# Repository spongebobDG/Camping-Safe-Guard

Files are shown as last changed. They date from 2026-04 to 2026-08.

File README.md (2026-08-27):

# Camping Safe Guard

ESP32·가스·온습도 센서와 TinyML을 이용해 캠핑 환경의 일산화탄소 위험을 감지하고 사용자에게 전달하는 캡스톤 프로젝트입니다.

> An embedded safety prototype that combines ESP32 sensor nodes, MQ-9 gas sensing, wireless telemetry, and TensorFlow Lite Micro experiments.

| 구분 | 내용 |
|---|---|
| 기간 | 2025.09–2025.12 |
| 구성 | 4인 개발팀 · 팀장 |
| 담당 | 시스템 설계, 모델 경량화, ESP32 펌웨어, ESP-NOW, 회로·3D 프린팅 케이스 제작 |
| 학술 성과 | KCC 2026 논문 심사 통과·포스터 세션 발표, 제1저자 |
| 논문 | 「제한된 엣지 환경에서의 일산화탄소 조기 경보를 위한 경량 1D-CNN 기반 웨어러블 시스템 설계」 |

## 프로젝트 요약

| 구분 | 내용 |
|---|---|
| 목적 | 캠핑 공간의 CO·온습도 상태 감지와 위험 단계 전달 |
| MCU | ESP32, ESP32-C3 |
| 센서 | MQ-9, DHT11 |
| 통신 | ESP-NOW 중심, BLE·모바일 UI prototype 실험 |
| Edge AI | TensorFlow Lite Micro 기반 시계열 위험도 추론 실험 |
| 기타 | OLED 표시, 모바일 HTML prototype, 3D printed enclosure, 배터리 승압 효율 자료 |

## 시스템 구조

```text
MQ-9 / DHT11
      │
      ▼
ESP32 sensor node ── calibration / TinyML inference ── status decision
      │                                                   │
      ├── OLED local display                              │
      └── ESP-NOW / BLE ──> ESP32-C3 receiver / mobile prototype
```

## 저장소에서 확인할 수 있는 구현

- MQ-9 clean-air calibration과 CO PPM 변환
- 온도·습도·가스 측정값을 결합한 상태 데이터
- sliding window 입력과 TensorFlow Lite Micro inference
- 정상·주의·위험 단계 판단 및 OLED 표시
- ESP-NOW 기반 센서 노드–수신 노드 통신 실험
- ESP32/ESP32-C3 케이스 STL과 18650 배터리 승압 효율 자료

가장 발전된 TinyML 실험 firmware는 [`src/esp32_ino/esp32_v4_ai/esp32_v4_ai.ino`](src/esp32_ino/esp32_v4_ai/esp32_v4_ai.ino)에 있습니다. 저장소에는 개발 과정의 여러 hardware revision이 함께 남아 있으므로 모든 `.ino` 파일을 최종 firmware로 해석하면 안 됩니다.

## TinyML 경로

```text
MQ-9 raw sequence
    └── normalization
        └── 60-step input buffer
            └── TFLite Micro inference
                └── probability + calibrated PPM safety rule
```

기준 firmware의 `N_STEPS = 60`이며, 2초 주기 샘플을 가정하면 최근 120초의 흐름을 입력으로 사용합니다.

## MCU 메모리 문제와 모델 전환

초기 LSTM 모델은 약 174KB로, 센서·ESP-NOW·OLED가 함께 동작하는 ESP32 환경에서 텐서 메모리 할당 문제가 발생했습니다. 캠핑 사고의 전조에서 중요한 것은 장기 상태보다 단시간의 농도 상승 패턴이라고 판단해 순환 구조를 1D-CNN으로 바꿨습니다. KCC 논문과 지원 포트폴리오에는 약 10KB까지 줄인 결과를 보고했습니다.

공개 저장소에는 개발 과정의 174KB 모델과 3–4KB대 실험 artifact 등 여러 revision이 함께 있습니다. 논문의 174KB→약 10KB 비교를 한 번에 재현하는 학습 notebook과 release는 아직 고정되어 있지 않으므로, 이 값은 **논문 보고 결과**로 표시하며 저장소 benchmark처럼 표현하지 않습니다.

## 하이브리드 안전 판단

| CO 구간 | 판단 방식 |
|---|---|
| 15 PPM 미만 | 센서 잡음 구간으로 보고 AI 결과를 사용하지 않음 |
| 15–50 PPM | AI 확률 0.5 초과 시 주의, 0.8 초과 시 위험 |
| 50–400 PPM | 규칙이 주의를 기본 보장하고 AI가 위험으로 격상 |
| 400 PPM 이상 | AI 결과와 무관하게 위험 상태 강제 |

합성 데이터 기반 HIL 급성 누출 시나리오에서는 절대 안전망 도달보다 약 8.5초 먼저 최고 경보가 발생했습니다. 이 값은 실제 CO 환경이나 인증 시험에서 얻은 성능이 아닙니다.

## 학술 성과

- 캡스톤 프로젝트
- 한국컴퓨터종합학술대회(KCC 2026) 논문 심사 통과
- KCC 2026 포스터 세션 발표
- 4인 개발팀 팀장·제1저자, 멘토·지도교수 포함 총 6인 저자

논문 제목은 「제한된 엣지 환경에서의 일산화탄소 조기 경보를 위한 경량 1D-CNN 기반 웨어러블 시스템 설계」입니다. 수상 실적은 없으며, 배포 권한이 확인되지 않은 학회 PDF는 저장소에 복제하지 않습니다.

## 디렉터리 안내

```text
Camping-Safe-Guard/
├── src/esp32_ino/        # ESP32/ESP32-C3 firmware revisions, model, training CSV
├── src/firmware/         # 초기 정리 과정에서 복제된 firmware tree
├── src/mobile-app/       # mobile display prototype
├── hardware/3d-models/   # enclosure STL revisions
└── docs/                 # battery boost efficiency data
```

`src/esp32_ino/`와 `src/firmware/esp32_ino/`의 중복은 후속 정리 대상입니다. 면접에서는 기준 firmware 경로와 revision별 목적을 먼저 설명합니다.

## 현재 한계

- 기준 hardware revision과 final firmware가 release로 고정되어 있지 않습니다.
- 센서 교정 환경과 실제 CO 기준 장비를 사용한 비교 시험이 문서화되지 않았습니다.
- 모델 평가와 MCU resource benchmark가 재현 가능한 형태로 정리되지 않았습니다.
- 약 8.5초 조기 경보는 합성 데이터 기반 HIL 결과이며 실환경 인증 성능이 아닙니다.
- 모바일 화면은 제품 앱이 아니라 prototype입니다.

## 안전 고지

이 프로젝트는 교육·연구용 prototype입니다. 인증된 일산화탄소 경보기, 환기 설비 또는 상용 안전 장치를 대체하지 않습니다.

## 면접용 요약

- **30초:** “4인 팀장으로 가스·온습도 센서부터 ESP32 edge inference, ESP-NOW, 회로와 케이스 제작까지 연결했고, 제1저자로 KCC 2026 포스터 세션에서 발표했습니다.”
- **기술 질문:** 센서 calibration, raw ADC와 PPM의 차이, TinyML 입력 정규화, 통신 장애 시 로컬 경보 유지 여부를 중심으로 설명합니다.

## Related Portfolio

[ROS 2 Robot Systems Software Portfolio](https://github.com/spongebobDG/robotics-software-portfolio)

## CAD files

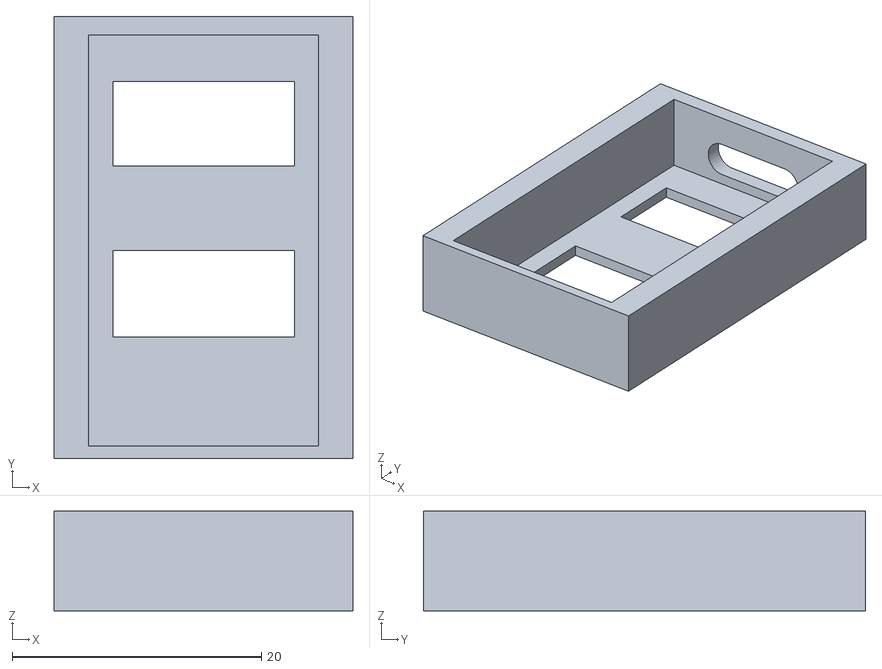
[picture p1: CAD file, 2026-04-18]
hardware/3d-models/esp32-c3_v2/esep32-c3_ctype.stl
24.0 x 35.5 x 8.00

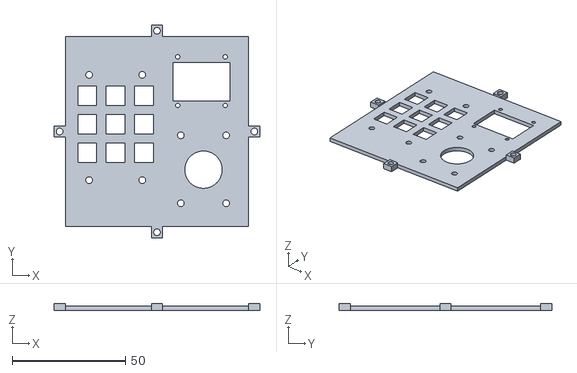
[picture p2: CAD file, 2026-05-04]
hardware/3d-models/esp32_v1/esp32_v1_2F_1.stl
91.0 x 94.0 x 3.00

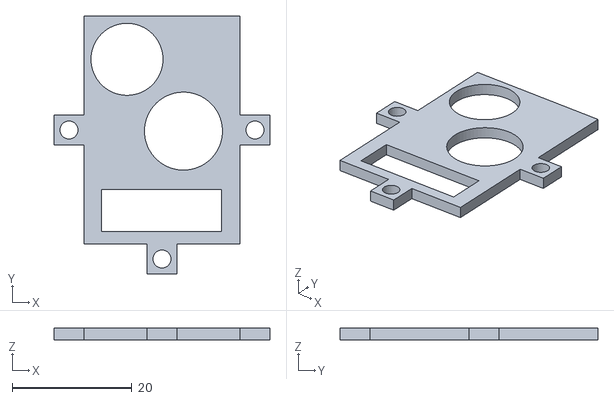
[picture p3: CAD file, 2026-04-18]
hardware/3d-models/esp32-c3_v2/esp32-c3_2F_v2.stl
36.0 x 43.0 x 2.00

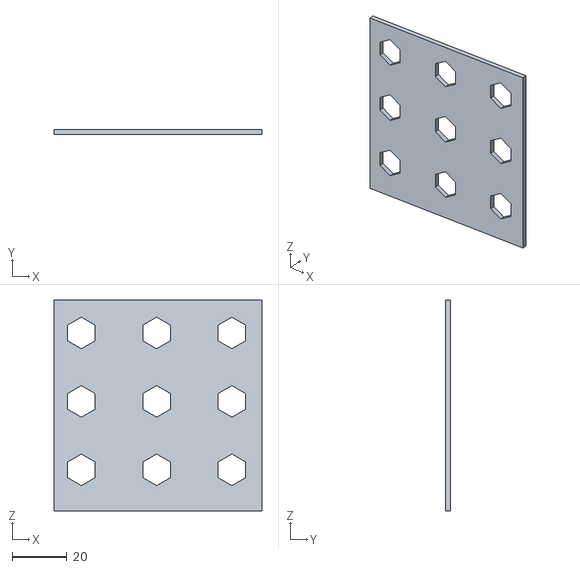
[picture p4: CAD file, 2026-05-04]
hardware/3d-models/esp32_v1/esp32_v1_-1F_1.stl
76.0 x 2.00 x 77.0

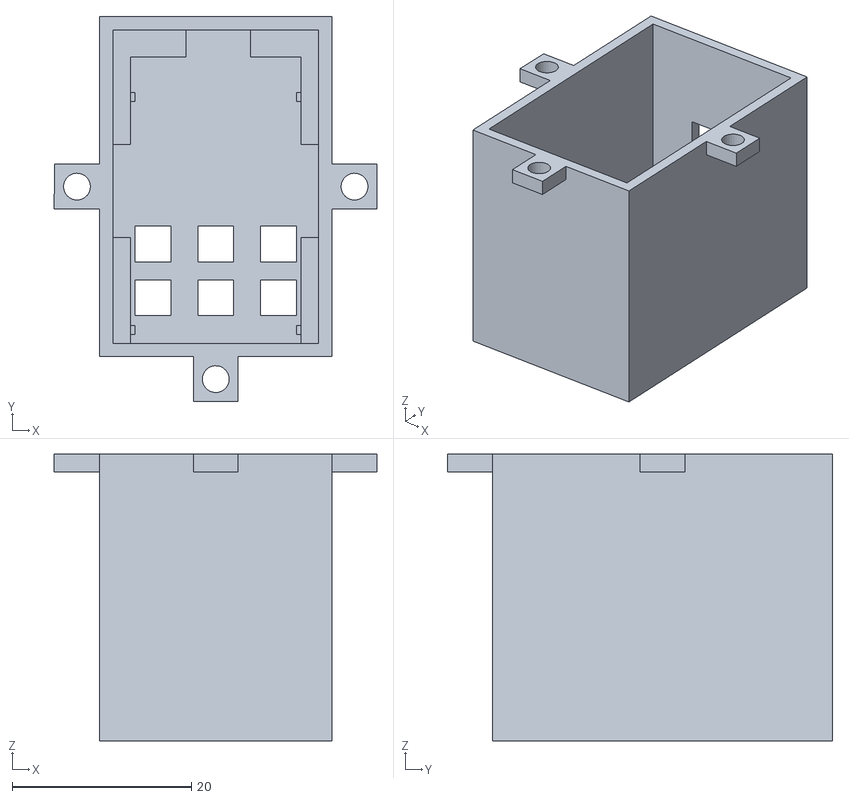
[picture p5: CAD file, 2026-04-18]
hardware/3d-models/esp32-c3_v2/esp32-c3_1F_v2.stl
36.1 x 43.0 x 32.0

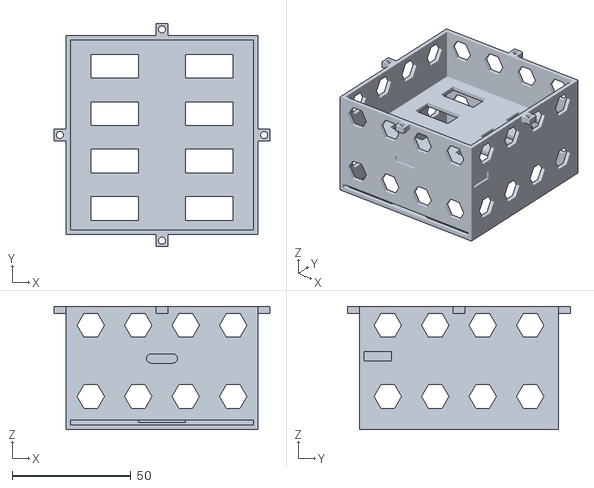
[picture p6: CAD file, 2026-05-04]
hardware/3d-models/esp32_v1/esp32_v1_1.stl
91.0 x 94.0 x 52.0

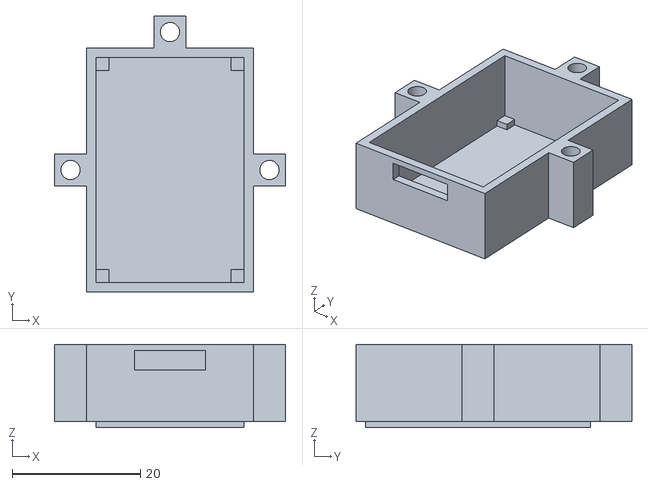
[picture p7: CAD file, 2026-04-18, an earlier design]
hardware/3d-models/esp32-c3_v1/esp32-c3_2F.stl
36.0 x 43.0 x 13.0

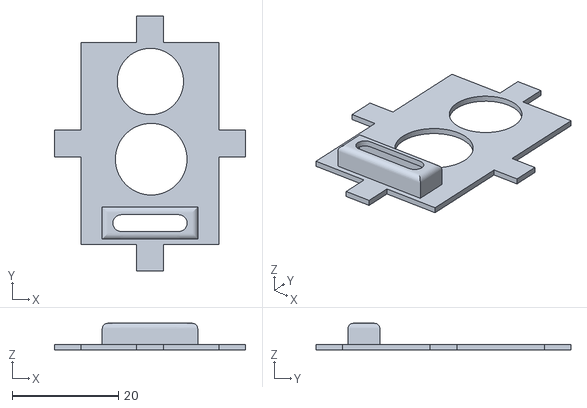
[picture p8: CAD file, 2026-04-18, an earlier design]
hardware/3d-models/esp32-c3_v1/esp32-3_4F.stl
36.0 x 48.0 x 5.00

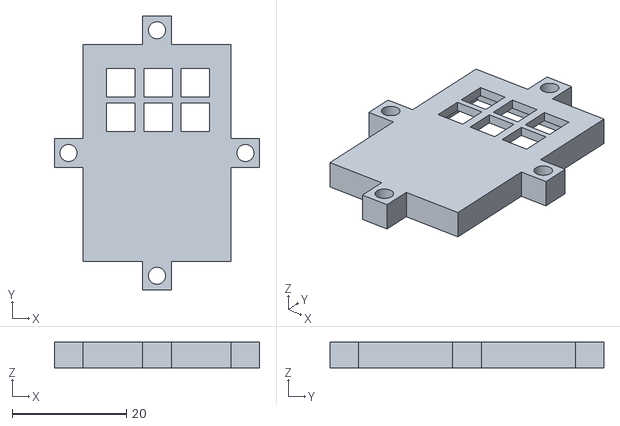
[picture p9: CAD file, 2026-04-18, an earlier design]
hardware/3d-models/esp32-c3_v1/esp32-c3_1F.stl
36.0 x 48.0 x 4.50

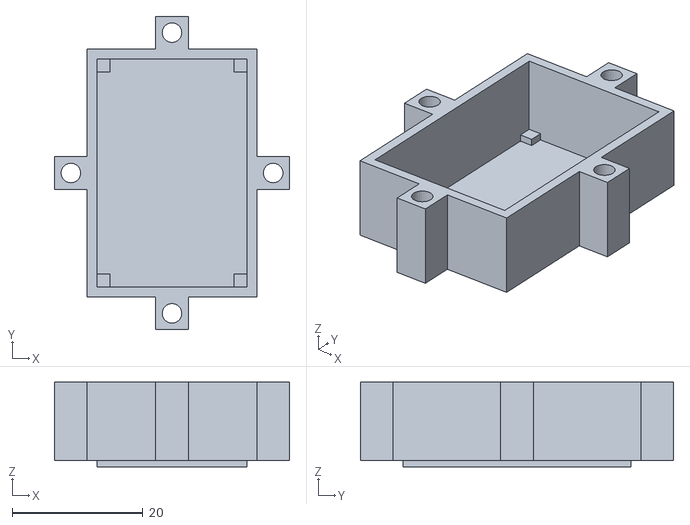
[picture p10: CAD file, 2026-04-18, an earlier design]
hardware/3d-models/esp32-c3_v1/esp32-c3_3F.stl
36.0 x 48.0 x 13.0

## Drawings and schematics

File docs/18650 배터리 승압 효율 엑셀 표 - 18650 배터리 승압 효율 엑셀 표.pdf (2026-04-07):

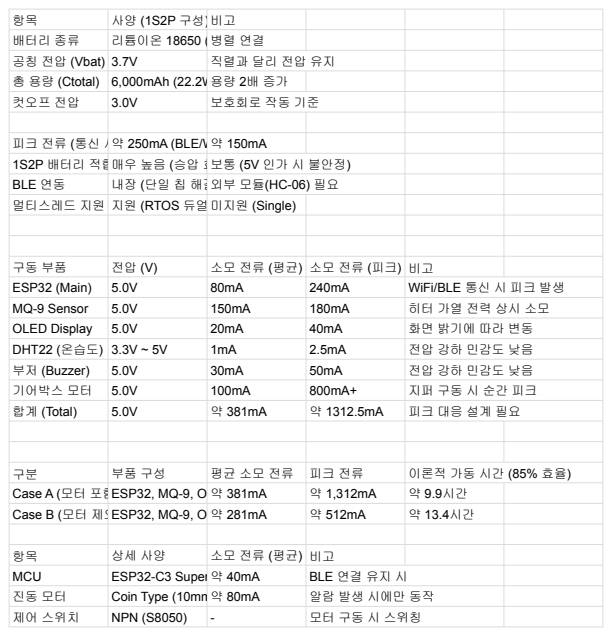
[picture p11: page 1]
배터리 종류; 리튬이온 18650 (3.7V 3000mAh × 2) 병렬 연결; 공칭 전압 (Vbat ) 3.7V; 직렬과 달리 전압 유지; 컷오프 전압; 보호회로 작동 기준; BLE 연동; 내장 (단일 칩 해결외부 모듈(HC-06) 필요; ESP32 (Main); WiFi/BLE 통신 시 피크 발생; MQ-9 Sensor; OLED Display; 화면 밝기에 따라 변동; DHT22 (온습도) 3.3V ~ 5V; 전압 강하 민감도 낮음; 부저 (Buzzer); 기어박스 모터; 합계 (Total); 이론적 가동 시간 (85% 효율); Case A (모터 포함ESP32, MQ-9, OLED, DHT22, 약 381mA; Case B (모터 제외ESP32, MQ-9, OLED, DHT22, 약 281mA; MCU; ESP32-C3 SuperMini 약 40mA; BLE 연결 유지 시; Coin Type (10mm)약 80mA; 알람 발생 시에만 동작; 제어 스위치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

총 용량 (Ctotal ) 6,000mAh (22.2Wh) 용량 2배 증가

피크 전류 (통신 시약 250mA (BLE/WiFi) 약 150mA
1S2P 배터리 적합성매우 높음 (승압 효율보통 (5V 인가 시 불안정)
멀티스레드 지원 지원 (RTOS 듀얼코어미지원 (Single)

합계 (평균) | BLE 상시 대기 | 약 40mA | 진동 미발생 기준
배터리 용량 | 연속 동작(BLE 온저전력 모드(Deep Sleep) 비고
150mAh | 약 3.7시간 | 약 15시간+ | 소형화 유리
200mAh | 약 5.0시간 | 약 20시간+ | 밸런스형
300mAh | 약 7.5시간 | 약 30시간+ | 다소 부피 커짐

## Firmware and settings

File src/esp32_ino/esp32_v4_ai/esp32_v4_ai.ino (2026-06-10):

#include <Wire.h>
#include <DHT.h>
#include <esp_now.h>
#include <WiFi.h>
#include <TensorFlowLite_ESP32.h>
#include "tensorflow/lite/micro/all_ops_resolver.h"
#include "tensorflow/lite/micro/micro_interpreter.h"
#include "tensorflow/lite/micro/micro_error_reporter.h"
// #include "camping_guard_model.h"
#include "camping_guard_model_v2.h"
// --- [추가] OLED 및 MQ 라이브러리 ---
#include <Adafruit_GFX.h>
#include <Adafruit_SSD1306.h>
#include <MQUnifiedsensor.h>

// --- 1. 상수 및 변수 설정 ---
#define DHTPIN 4
#define DHTTYPE DHT11
DHT dht(DHTPIN, DHTTYPE);

#define MQ9_PIN 34
#define BUZZER_PIN 25

// OLED 설정
#define SCREEN_WIDTH 128
#define SCREEN_HEIGHT 64
#define OLED_RESET -1
Adafruit_SSD1306 display(SCREEN_WIDTH, SCREEN_HEIGHT, &Wire, OLED_RESET);

// MQ-9 센서 설정 (CO 가스 기준)
#define Board ("ESP-32")
#define Voltage_Resolution (3.3)
#define ADC_Bit_Resolution (12)
#define RatioMQ9CleanAir (9.6)
MQUnifiedsensor MQ9(Board, Voltage_Resolution, ADC_Bit_Resolution, MQ9_PIN, "MQ-9");

// 파이썬에서 추출한 실제 값 적용 (가스 단일 특성)
const float means[] = { 2027.71 };
const float stds[] = { 1535.26 };

const int N_STEPS = 60;
const int N_FEATURES = 1;
float input_buffer[N_STEPS * N_FEATURES] = {0,};

// TFLite 관련
const int kArenaSize = 16 * 1024;
uint8_t tensor_arena[kArenaSize];
tflite::AllOpsResolver resolver;
const tflite::Model* model;
tflite::MicroInterpreter* interpreter;
TfLiteTensor* input;
TfLiteTensor* output;

// ESP-NOW 송신용 주소70:AF:09:21:EC:E4
uint8_t broadcastAddress[] = {0x70, 0xAF, 0x09, 0x21, 0xEC, 0xE4};
typedef struct struct_message {
    float temp; float humid; int gas; int status; // 구조체의 gas는 이제 PPM 값을 담습니다.
} struct_message;
struct_message myData;
esp_now_peer_info_t peerInfo;
// 1. 송신 상태 확인용 콜백 함수 추가
void OnDataSent(const uint8_t *mac_addr, esp_now_send_status_t status) {
  Serial.print("\r\nLast Packet Send Status: ");
  Serial.println(status == ESP_NOW_SEND_SUCCESS ? "Delivery Success" : "Delivery Fail");
}
// --- 2. 초기화 함수 ---
void setup() {


    Serial.begin(115200);
    dht.begin();
    pinMode(BUZZER_PIN, OUTPUT);

    


    // OLED 초기화
    if(!display.begin(SSD1306_SWITCHCAPVCC, 0x3C)) {
        Serial.println(F("OLED 초기화 실패"));
    }
    display.clearDisplay();
    display.setTextColor(WHITE);
    
    // MQ-9 초기화 및 캘리브레이션 (깨끗한 공기에서 영점 잡기)
    MQ9.setRegressionMethod(1); // _PPM =  a*ratio^b
    MQ9.setA(599.65); MQ9.setB(-2.244); // 일산화탄소(CO) 공식 설정
    MQ9.init();
    
    Serial.print("MQ-9 캘리브레이션 중...");
    float calcR0 = 0;
    for(int i = 1; i <= 10; i++) {
        MQ9.update();
        calcR0 += MQ9.calibrate(RatioMQ9CleanAir);
        delay(100);
    }
    MQ9.setR0(calcR0 / 10);
    Serial.println(" 완료!");

    // TFLite 초기화
    static tflite::MicroErrorReporter micro_error_reporter;
    model = tflite::GetModel(camping_guard_model);
    static tflite::MicroInterpreter static_interpreter(
        model, resolver, tensor_arena, kArenaSize, &micro_error_reporter, nullptr, nullptr
    );
    interpreter = &static_interpreter;
    interpreter->AllocateTensors();
    input  = interpreter->input(0);
    output = interpreter->output(0);
    
    // WiFi & ESP-NOW
    WiFi.mode(WIFI_STA);
    if (esp_now_init() == ESP_OK) {
        esp_now_register_send_cb(OnDataSent);
        memcpy(peerInfo.peer_addr, broadcastAddress, 6);
        peerInfo.channel = 0; 
        peerInfo.encrypt = false;
        esp_now_add_peer(&peerInfo);
    }
}

// --- 3. 메인 루프 ---
void loop() {
    // 예열 타이머 (OLED 및 시리얼에 표시)
    static const unsigned long WARMUP_TIME = 60000; 

    unsigned long start_time = micros();
    TfLiteStatus invoke_status = interpreter->Invoke();
    unsigned long end_time = micros();
    Serial.print("Inference Time: ");
    Serial.print(end_time - start_time);
    Serial.println(" us");

    if (millis() < WARMUP_TIME) {
        // [추가된 코드] 시리얼 모니터에도 남은 시간을 출력합니다!
        Serial.printf("예열 중... 남은 시간: %lu 초\n", (WARMUP_TIME - millis()) / 1000);
        
        display.clearDisplay();
        display.setTextSize(1);
        display.setCursor(0, 10);
        display.println("Warming Up Sensor...");
        display.setCursor(0, 30);
        display.printf("Wait: %lu sec", (WARMUP_TIME - millis()) / 1000);
        display.display();
        delay(1000);
        return; // 60초가 지나기 전까지는 알람/통신/AI 판단을 강제로 막음
    }

    // 데이터 읽기
    float t = dht.readTemperature();
    float h = dht.readHumidity();
    
    // [핵심 1] AI를 위한 Raw ADC 읽기
    int gas_raw = analogRead(MQ9_PIN);
    
    // [핵심 2] 사용자를 위한 PPM 읽기
    MQ9.update();
    float gas_ppm = MQ9.readSensor(); 

    // 슬라이딩 윈도우 업데이트
    for (int i = 0; i < (N_STEPS - 1) * N_FEATURES; i++) {
        input_buffer[i] = input_buffer[i + N_FEATURES];
    }
    
    // [버그 수정 완료!] t가 아니라 gas_raw를 넣어야 합니다.
    input_buffer[(N_STEPS - 1) * N_FEATURES + 0] = (gas_raw - means[0]) / stds[0];

    // 입력 텐서에 복사
    for (int i = 0; i < N_STEPS * N_FEATURES; i++) {
        input->data.f[i] = input_buffer[i];
    }
// --- AI 추론 및 하이브리드 판단 ---
    if (interpreter->Invoke() == kTfLiteOk) {
        float prediction = output->data.f[0];
        int currentStatus = 0;

        // 1. 하드웨어적 절대 안전망 (PPM 기준 Failsafe)
        if (gas_ppm >= 400.0) {
            currentStatus = 2; // 400 PPM 이상: 구토/실신 위험 (즉시 알람)
        } 
        else if (gas_ppm >= 50.0) {
            currentStatus = 1; // 50 PPM 이상: 장시간 노출 시 두통 (주의)
            // AI가 가파른 상승을 감지했다면 상태 격상
            if (prediction > 0.8) currentStatus = 2; 
        }
        // 2. 평상시 AI 사전 예측 (Early Warning) - 데드존(Deadzone) 적용
        else {
            // [핵심 수정] 가스가 최소 15 PPM 이상 감지될 때만 AI의 예측을 신뢰합니다.
            // 15 PPM 미만은 물리적으로 완벽히 안전하므로 AI의 헛것(유령 알람)을 무시합니다.
            if (gas_ppm > 15.0) { 
                if (prediction > 0.8) currentStatus = 2;      // 위험 (가파른 상승세)
                else if (prediction > 0.5) currentStatus = 1; // 주의
                else currentStatus = 0;                       // 정상
            } else {
                currentStatus = 0; // 완벽한 안전 구역 (AI 무시)
            }
        }

        // 결과 전송 (ESP-NOW)
        myData.temp = t; 
        myData.humid = h;
        myData.gas = (int)gas_ppm; 
        myData.status = currentStatus;
        esp_now_send(broadcastAddress, (uint8_t *) &myData, sizeof(myData));

        Serial.printf("T:%.1f H:%.1f PPM:%d | AI Prob: %.2f | Stat: %d\n", t, h, (int)gas_ppm, prediction, currentStatus);

        // 로컬 알람
        if (currentStatus == 2) tone(BUZZER_PIN, 2000); 
        else noTone(BUZZER_PIN);

        // --- OLED 디스플레이 출력 ---
        display.clearDisplay();
        display.setTextSize(1);
        display.setCursor(0,0);
        display.println("--- CAMPING GUARD ---");
        
        display.setCursor(0, 15);
        display.printf("Temp : %.1f C", t);
        display.setCursor(0, 25);
        display.printf("Humid: %.1f %%", h);
        
        display.setCursor(0, 45);
        display.setTextSize(2);
        // 상태에 따라 출력 문구 변경
        if(currentStatus == 2)      display.printf("CO: %d PPM !", (int)gas_ppm);
        else if(currentStatus == 1) display.printf("CO: %d PPM *", (int)gas_ppm);
        else                        display.printf("CO: %d PPM", (int)gas_ppm);
        
        display.display();
    }
    delay(2000); 
}

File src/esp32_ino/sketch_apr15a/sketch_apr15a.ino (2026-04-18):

#include <esp_now.h>
#include <WiFi.h>
#include <driver/gpio.h>  // ★ gpio_hold 함수용

#define BUZZER_PIN    5
#define VIBRATOR_PIN  4
#define LED_PIN       6

RTC_DATA_ATTR int gasHistory[3] = {0, 0, 0};
RTC_DATA_ATTR int nextSleepInterval = 10;

typedef struct struct_message {
    float temp; float humid; int gas; int status;
} struct_message;

struct_message incomingReadings;
volatile bool isNewData = false;

void OnDataRecv(const esp_now_recv_info *info, const uint8_t *incomingData, int len) {
  memcpy(&incomingReadings, incomingData, sizeof(incomingReadings));
  isNewData = true;
}

void dangerAlarm() {
  for (int repeat = 0; repeat < 4; repeat++) {
    digitalWrite(VIBRATOR_PIN, HIGH);
    for (int f = 2700; f <= 3200; f += 50) { tone(BUZZER_PIN, f); delay(15); }
    for (int f = 3200; f >= 2700; f -= 50) { tone(BUZZER_PIN, f); delay(15); }
    digitalWrite(VIBRATOR_PIN, LOW);
    noTone(BUZZER_PIN);
    delay(80);
  }
}

void warningAlarm() {
  for (int i = 0; i < 3; i++) {
    tone(BUZZER_PIN, 3000); delay(500);
    noTone(BUZZER_PIN);     delay(250);
  }
}

void setup() {

    // 슬립 전 확실히 끄기
  digitalWrite(VIBRATOR_PIN, LOW);
  noTone(BUZZER_PIN);
  digitalWrite(LED_PIN, LOW);

  
  // ★ 1순위: hold 해제 → 이전 슬립에서 잠긴 핀을 먼저 풀어야 제어 가능
  gpio_hold_dis((gpio_num_t)VIBRATOR_PIN);
  gpio_hold_dis((gpio_num_t)LED_PIN);

  // ★ 즉시 LOW 고정
  gpio_reset_pin((gpio_num_t)VIBRATOR_PIN);
  gpio_set_direction((gpio_num_t)VIBRATOR_PIN, GPIO_MODE_OUTPUT);
  gpio_set_level((gpio_num_t)VIBRATOR_PIN, 0);
  gpio_pulldown_en((gpio_num_t)VIBRATOR_PIN);

  Serial.begin(115200);
  pinMode(BUZZER_PIN, OUTPUT);
  pinMode(VIBRATOR_PIN, OUTPUT);
  pinMode(LED_PIN, OUTPUT);

  digitalWrite(VIBRATOR_PIN, LOW);
  noTone(BUZZER_PIN);
  digitalWrite(LED_PIN, LOW);

  WiFi.mode(WIFI_STA);
  if (esp_now_init() == ESP_OK) {
    esp_now_register_recv_cb(OnDataRecv);
  }

  unsigned long startWait = millis();
  while (millis() - startWait < 2500) {
    if (isNewData) break;
    delay(10);
  }

  if (isNewData) {
    int receivedStatus = incomingReadings.status;

    gasHistory[2] = gasHistory[1];
    gasHistory[1] = gasHistory[0];
    gasHistory[0] = incomingReadings.gas;

    Serial.printf("Raw: %d, Status(from main): %d\n",
                  incomingReadings.gas, receivedStatus);

    if (receivedStatus == 2) {
      Serial.println("LEVEL 2: DANGER");
      digitalWrite(LED_PIN, HIGH);
      nextSleepInterval = 3;
      dangerAlarm();
      digitalWrite(LED_PIN, LOW);
    }
    else if (receivedStatus == 1) {
      Serial.println("LEVEL 1: WARNING");
      nextSleepInterval = 7;
      warningAlarm();
    }
    else {
      Serial.println("LEVEL 0: SAFE");
      nextSleepInterval = 15;
    }
  } else {
    Serial.println("No Signal. Sleep...");
    nextSleepInterval = 10;
  }

  // 슬립 전 확실히 끄기
  digitalWrite(VIBRATOR_PIN, LOW);
  noTone(BUZZER_PIN);
  digitalWrite(LED_PIN, LOW);

  // ★ LOW 상태 그대로 잠그기 → 슬립 중 + 다음 부팅 첫 순간까지 LOW 유지
  gpio_hold_en((gpio_num_t)VIBRATOR_PIN);
  gpio_hold_en((gpio_num_t)LED_PIN);

  Serial.printf("Deep Sleep: %d sec\n", nextSleepInterval);
  esp_sleep_enable_timer_wakeup((uint64_t)nextSleepInterval * 1000000ULL);
  esp_deep_sleep_start();
}

void loop() {}

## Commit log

2026-04-06 feat: 프로젝트 초기 구성 및 소스코드 업로드
2026-04-07 docs: 문서 업데이트 (2026-04-07)
    [18650 배터리 승압 효율 엑셀 표.xlsx]
2026-04-18 Add 3D models for Camping-Safe-Guard hardware
    [esp32-3_4F.stl, esp32-c3_1F.stl, esp32-c3_2F.stl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]
2026-04-18 esp32-c3 .ino update
2026-04-19 feat: TinyML 기반 가스 탐지 모델 및 하이브리드 안전 시스템 구현
2026-04-20 esp32 ai version4 add
2026-05-04 hardware esp32_v1 upload
    [esp32_v1_-1F_1.stl, esp32_v1_1.stl, esp32_v1_2F_1.stl]
2026-06-10 esp32 ino update
    [master_training_data_with_labels.csv]
